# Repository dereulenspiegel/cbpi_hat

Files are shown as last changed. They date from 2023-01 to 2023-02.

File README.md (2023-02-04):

# CraftBeerPi Hat
This is a Raspberry Pi hat meant for use with [CraftBeerPi](https://github.com/craftbeerpi/craftbeerpi4).
It's created with [EasyEDA](https://easyeda.com/) and optimized for production via 
[JLCPCB](https://jlcpcb.com/).

This project is [certified](https://certification.oshwa.org/de000132.html) as open source
hardware by the [OSHWA](https://www.oshwa.org/) under the UID DE000132.

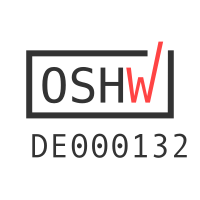
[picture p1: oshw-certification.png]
OSHWA certifcation logo


## Development

Currently this project is designed with [EasyEDA](https://easyeda.com/). You can find
all necessary files in the folder `easyeda`. When modifying this project please
respect the CERN-OHL-S license used in this project.

## Features

* Slots for up to 5 MAX31865 modules for PT100/PT1000 measurements
* 7 digital outputs with up to 1 amp of output power
* All 7 outputs have flyback diodes to drive inductive loads like solenoids
* All 7 outputs have resettable fuses for extra protection
* RTC so the Raspberry Pi doesn't loose its time in offline installations
* QWIIC connector to hookup additional sensors and actors following the 
  SparkFun QWIIC specification
* OneWire connection for additional sensors
* Can operate on 12-24V, digital outputs operate directly on input voltage
* Reverse voltage protection (but please be still be careful)

Please note that the digital outputs are inverted in logic due to the push pull stage, but
CraftBeerPi supports inverting GPIO actors.

# Polarity of connectors!!!

This board is powered by 12-24V and provides some reverse polarity protection. But still
please be careful when wiring up the board. Looking at the front of a connector the left
side of a connector is always the negative side and the right side of a connector is always
the positive side!

PCB:

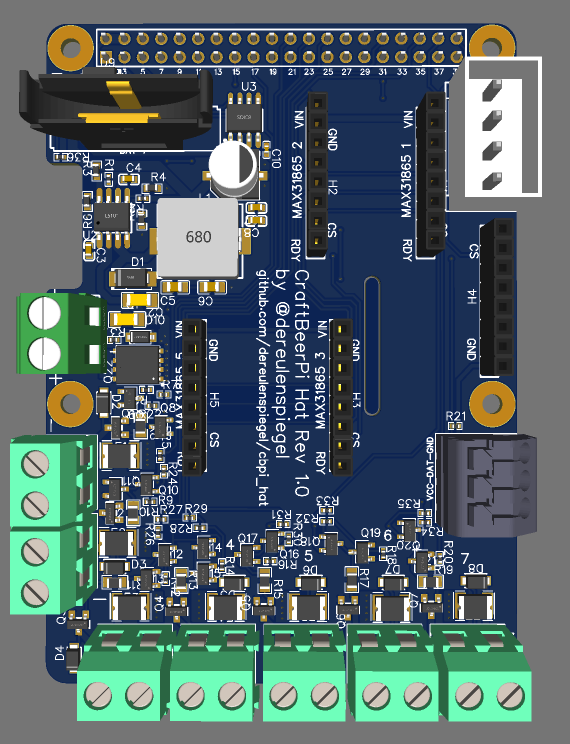
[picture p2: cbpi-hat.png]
Image of PCB rendering


Schematic:

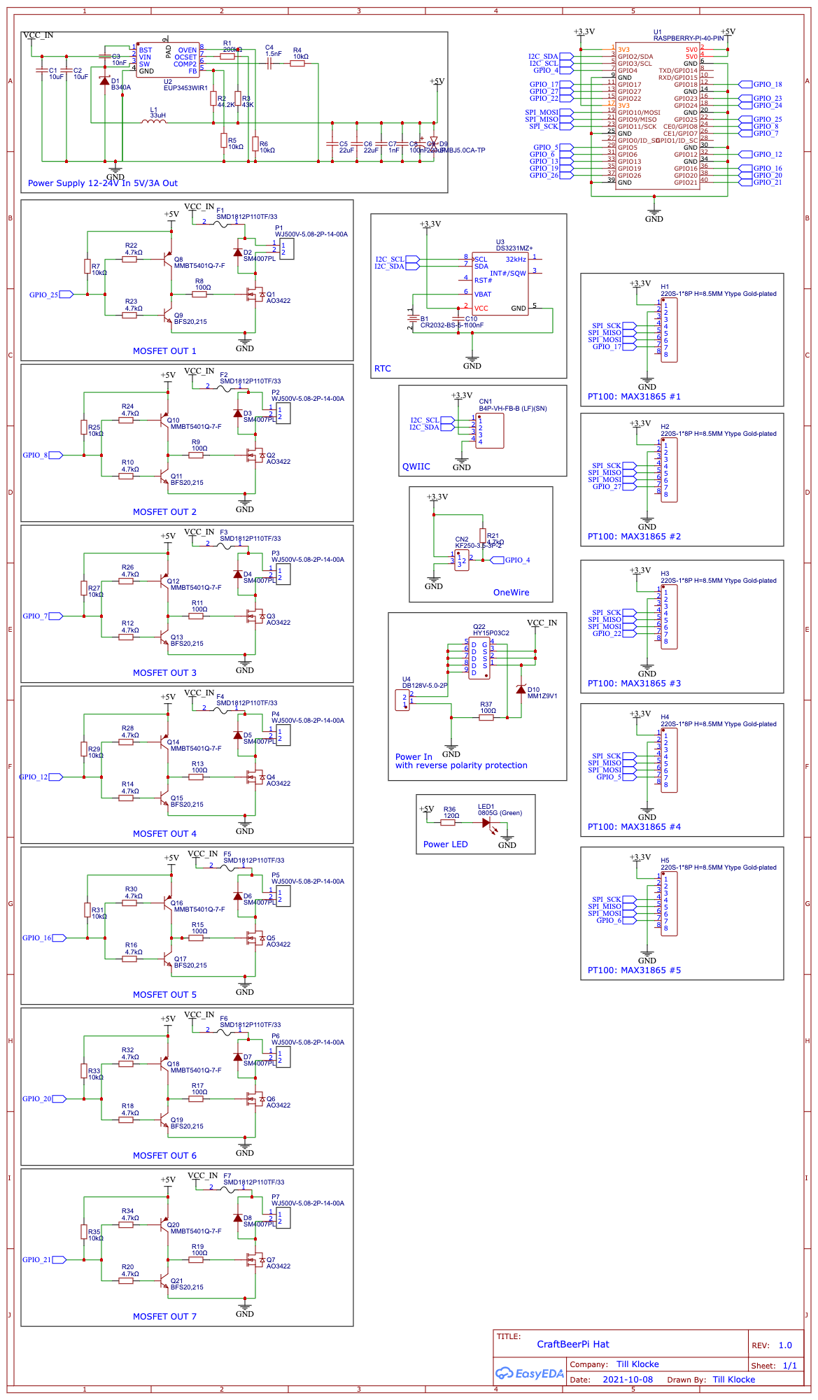
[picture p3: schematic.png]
Schematic


## PIN configuration

### Digital outputs

Digital outputs are counted starting on the most left. Outputs 2,3 and 7 are marked on the edge of
the PCBs upper layer. On the bottom layer every output is numbered and the polarity marked. On the
upper layer polarity markings are only next to the outer most ports on each side. But polarity is
always left side negative, right side positive.

| Output # | GPIO |
|---|---|
| 1 | 25 |
| 2 |  8 |
| 3 |  7 |
| 4 | 12 |
| 5 | 16 |
| 6 | 20 |
| 7 | 21 |

### MAX31865 modules

The MAX31865 modules are connected via SPI and each have a different CS-Pin. Modules
1,2,3,5 are mounted with the upper side facing left (towards the power connector and the SD-card
slot of the Raspberry Pi). Module 5 is flipped 180°. Every module connector has the first two and
last two pins marked with the same markings as the module to ensure the correct orientation.

| Modules # | GPIO CS |
|---|---|
| 1 | 17 |
| 2 | 27 |
| 3 | 22 |
| 4 |  5 |
| 5 |  6 |

### OneWire

The OneWire data line is connected to `GPIO 4`. The pins on the connector are marked behind the connector
on the top side of the PCB. They are, from left to right `VCC` - `DAT` - `GND`. A 4.7k pull up is
already provided on the board.
To enable OneWire support on a Raspberry Pi you need to add
```
dtoverlay=w1-gpio,gpiopin=4
```
to your config.txt

### RealTime Clock

The RTC (DS3231) is connected via I2C and should be usable by adding
```
dtparam=i2c_arm=on
dtoverlay=i2c-rtc,ds3231
```
to your config.txt

## Known Caveats

### Revision 1.0

* On revision 1.0 outputs 2 and 3 are mapped to chip enable pins of SPI0. Users need to disable CE pins on SPI0
* On revision 1.0 outputs are not in the desired off state during and directly after boot

To solve these issues the Raspberry Pi can be configured via config.txt.
With adding `dtoverlay=spi0-0cs` to the config.txt you can disable the hardware CE pins for SPI 0, freeing up GPIO 7 and 8
making Output 2 and 3 freely usabel.
With `gpio=25,7,8,12,16,20,21=op,dh` in the config.txt we set all pins controlling powered outputs to output and pull them high
as early as possible to disable the outputs. During power on there might be less than a second where the outputs might be enabled.

## Full config.txt additions for this board

```
# Enable SPI
dtparam=spi=on
# Enable 1-Wire
dtoverlay=w1-gpio,gpiopin=4
# Enable RTC
dtparam=i2c_arm=on
dtoverlay=i2c-rtc,ds3231
# Disable SPI0 CE pins
dtoverlay=spi0-0cs
# Disable outputs on boot
gpio=25,7,8,12,16,20,21=op,dh
```

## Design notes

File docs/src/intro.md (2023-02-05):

# Introduction

This CraftBeerPi Hat is mainly intended for brewery automation. It can be used for other use cases
involving digital outputs and sensor inputs, however this is out of scope of this project.
The hat should be compatible with other Single Board Computer systems following the 40 pin GPIO
layout introduced by the Raspberry Pi, but this is not guaranteed and untested.

The Hat has currently the following features:

* Input voltage of 12V - 24V
* DC-DC converter to power the Raspberry Pi from input voltage
* Reverse voltage protection on input
* Digital outputs operate on input voltage and provide up to 1 amp of output current
* Digital outputs are secured by flyback diode to be able to switch inductive loads
* Digital outputs are secured by a PTC resettable fuse to protect from over currents
* RTC for the Raspberry Pi
* OneWire connector to add additional sensors
* Possibility to mount a QWIIC connector for additional sensors and actors
* 5 slots for MAX31865 PT100/PT1000 converter

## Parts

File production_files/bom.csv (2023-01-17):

ID | Name | Designator | Footprint | Quantity | Manufacturer Part | Manufacturer | Supplier | Supplier Part | Price
1 | MM1Z9V1 | D10 | SOD-123_L2.7-W1.6-LS3.7-RD | 1 | MM1Z9V1 | ST(先科) | LCSC | C87636 | 0.002
2 | HY15P03C2 | Q22 | DFN-8_L5.9-W5.2-P1.27-LS6.2-BL | 1 | HY15P03C2 | HUAYI(华羿微) | LCSC | C123687
3 | 100Ω | R37 | R0402 | 1 | 0402WGF1000TCE | UNI-ROYAL(厚声) | LCSC | C25076
4 | 0805G (Green) | LED1 | LED0805-RD_GREEN | 1 | KT-0805翠绿 (SMT业务专用) | null | LCSC | C2297
5 | 120Ω | R36 | R0402 | 1 | 0402WGF1200TCE | UNI-ROYAL(厚声) | LCSC | C25079
6 | 1nF | C7 | C0603 | 1 | CC0603KRX7R9BB102 | YAGEO(国巨) | LCSC | C100040
7 | 100nF | C8 | C0603 | 1 | 0603B104K500NT | FH(风华) | LCSC | C30926
8 | 220uF | C9 | CAP-SMD_BD6.3-L6.6-W6.6-FD | 1 | RVE1A221M0605 | ROQANG(容强) | LCSC | C131120 | 0.008
9 | SMBJ5.0CA-TP | D9 | SMB_L4.6-W3.6-LS5.3-BI | 1 | SMBJ5.0CA-TP | MCC(美微科) | LCSC | C78757
10 | SMD1812P110TF/33 | F1,F2,F3,F4,F5,F6,F7 | F1812 | 7 | SMD1812P110TF/33 | RUILON(瑞隆源) | LCSC | C21000 | 0.02
11 | MMBT5401Q-7-F | Q8,Q10,Q12,Q14,Q16,Q18,Q20 | SOT-23-3_L3.0-W1.7-P0.95-LS2.9-BR | 7 | MMBT5401Q-7-F | DIODES(美台) | LCSC | C81569
12 | BFS20,215 | Q9,Q11,Q13,Q15,Q17,Q19,Q21 | SOT-23-3_L2.9-W1.6-P1.90-LS2.8-BR | 7 | BFS20,215 | Nexperia(安世) | LCSC | C73088
13 | 10kΩ | R7,R25,R27,R29,R31,R33,R35 | R0402 | 7 | 0402WGF1002TCE | UNI-ROYAL(厚声) | LCSC | C25744
14 | 4.7kΩ | R10,R12,R14,R16,R18,R20,R22,R23,R24,R26,R28,R30,R32,R34,R21 | R0402 | 15 | 0402WGF4701TCE | UNI-ROYAL(厚声) | LCSC | C25900
15 | KF250-3.5-3P-2 | CN2 | CONN-TH_3P-P3.50_KF250-3.5-3P-2 | 1 | KF250-3.5-3P-2 | Cixi Kefa Elec | LCSC | C475164 | 0.029
16 | CR2032-BS-5-1 | B1 | BAT-TH_CR2032-BS-5-1 | 1 | CR2032-BS-5-1 | Q&J | LCSC | C70379 | 0.018
17 | 10uF | C1,C2 | C1206 | 2 | CL31A106KBHNNNE | SAMSUNG(三星) | LCSC | C13585 | 0.005
18 | 10nF | C3 | C0603 | 1 | 0603B103K500NT | FH(风华) | LCSC | C57112
19 | 1.5nF | C4 | C0603 | 1 | 0603B152K500NT | FH(风华) | LCSC | C1595 | 0.001
20 | 22uF | C5,C6 | C0805 | 2 | CL21A226MAQNNNE | SAMSUNG(三星) | LCSC | C45783 | 0.004
21 | B4P-VH-FB-B (LF)(SN) | CN1 | CONN-TH_B4P-VH-FB-B-LF-SN | 1 | B4P-VH-FB-B(LF)(SN) | JST | LCSC | C157995 | 0.043
22 | B340A | D1 | SMA_L4.3-W2.6-LS5.2-RD | 1 | B340A | MDD | LCSC | C64982 | 0.007
23 | SM4007PL | D2,D3,D4,D5,D6,D7,D8 | SOD-123F_L2.8-W1.8-LS3.7-RD | 7 | SM4007PL | MDD | LCSC | C64898 | 0.001
24 | 220S-1*8P H=8.5MM Ytype Gold-plated | H1,H2,H3,H4,H5 | HDR-TH_8P-P2.54-V-F-1 | 5 | 220S-1*8P H=8.5MM Ytype Gold-plated | Ckmtw | LCSC | C124416 | 0.023
25 | 33uH | L1 | IND-SMD_L11.5-W10.0 | 1 | SMMS1050-330M | SXN(顺翔诺) | LCSC | C149547 | 0.045
26 | WJ500V-5.08-2P-14-00A | P1,P2,P3,P4,P5,P6,P7 | CONN-TH_2P-P5.00_WJ500V-5.08-2P | 7 | WJ500V-5.08-2P | KANGNEX(康奈克斯电气) | LCSC | C8465 | 0.018
27 | AO3422 | Q1,Q2,Q3,Q4,Q5,Q6,Q7 | SOT-23_L2.9-W1.3-P1.90-LS2.4-BR | 7 | AO3422 | AOS | LCSC | C37130 | 0.036
28 | 200kΩ | R1 | R0402 | 1 | AR02BTC2003 | Viking(光颉) | LCSC | C317930 | 0.004
29 | 44.2K | R2 | R0402 | 1 | AC0402FR-0744K2L | YAGEO(国巨) | LCSC | C227086
30 | 43K | R3 | R0603 | 1 | RC0603FR-0743KL | YAGEO(国巨) | LCSC | C137719
31 | 10kΩ | R4,R5,R6 | R0603 | 3 | RMC060310KFN | Tyohm(幸亚电阻) | LCSC | C269701
32 | 100Ω | R8,R9,R11,R13,R15,R17,R19 | R0805 | 7 | 0805W8F1000T5E | UNI-ROYAL(厚声) | LCSC | C17408
33 | EUP3453WIR1 | U2 | SOIC-8_L4.9-W3.9-P1.27-LS6.0-BL-EP3.1 | 1 | EUP3453WIR1 | Eutech Microelectronics | LCSC | C311687
34 | DS3231MZ+ | U3 | SOIC-8_L4.9-W3.9-P1.27-LS6.0-BL | 1 | DS3231MZ+TRL | MAXIM(美信) | LCSC | C107410 | 0.816
35 | DB128V-5.0-2P | U4 | CONN-TH_2P-P5.00_DB128V-5.0-2P | 1 | DB128V-5.0-2P | DIBO | LCSC | C395860 | 0.023
36 | RASPBERRY-PI-40-PIN | U1 | 2*20P_RASPBERRY_PI_HEADER | 1 | C35165 | BOOMELE | LCSC | C35165 | 0.159
37 | 100nF | C10 | C0402_NEW | 1 | CL05B104KO5NNNC | SAMSUNG(三星) | LCSC | C1525

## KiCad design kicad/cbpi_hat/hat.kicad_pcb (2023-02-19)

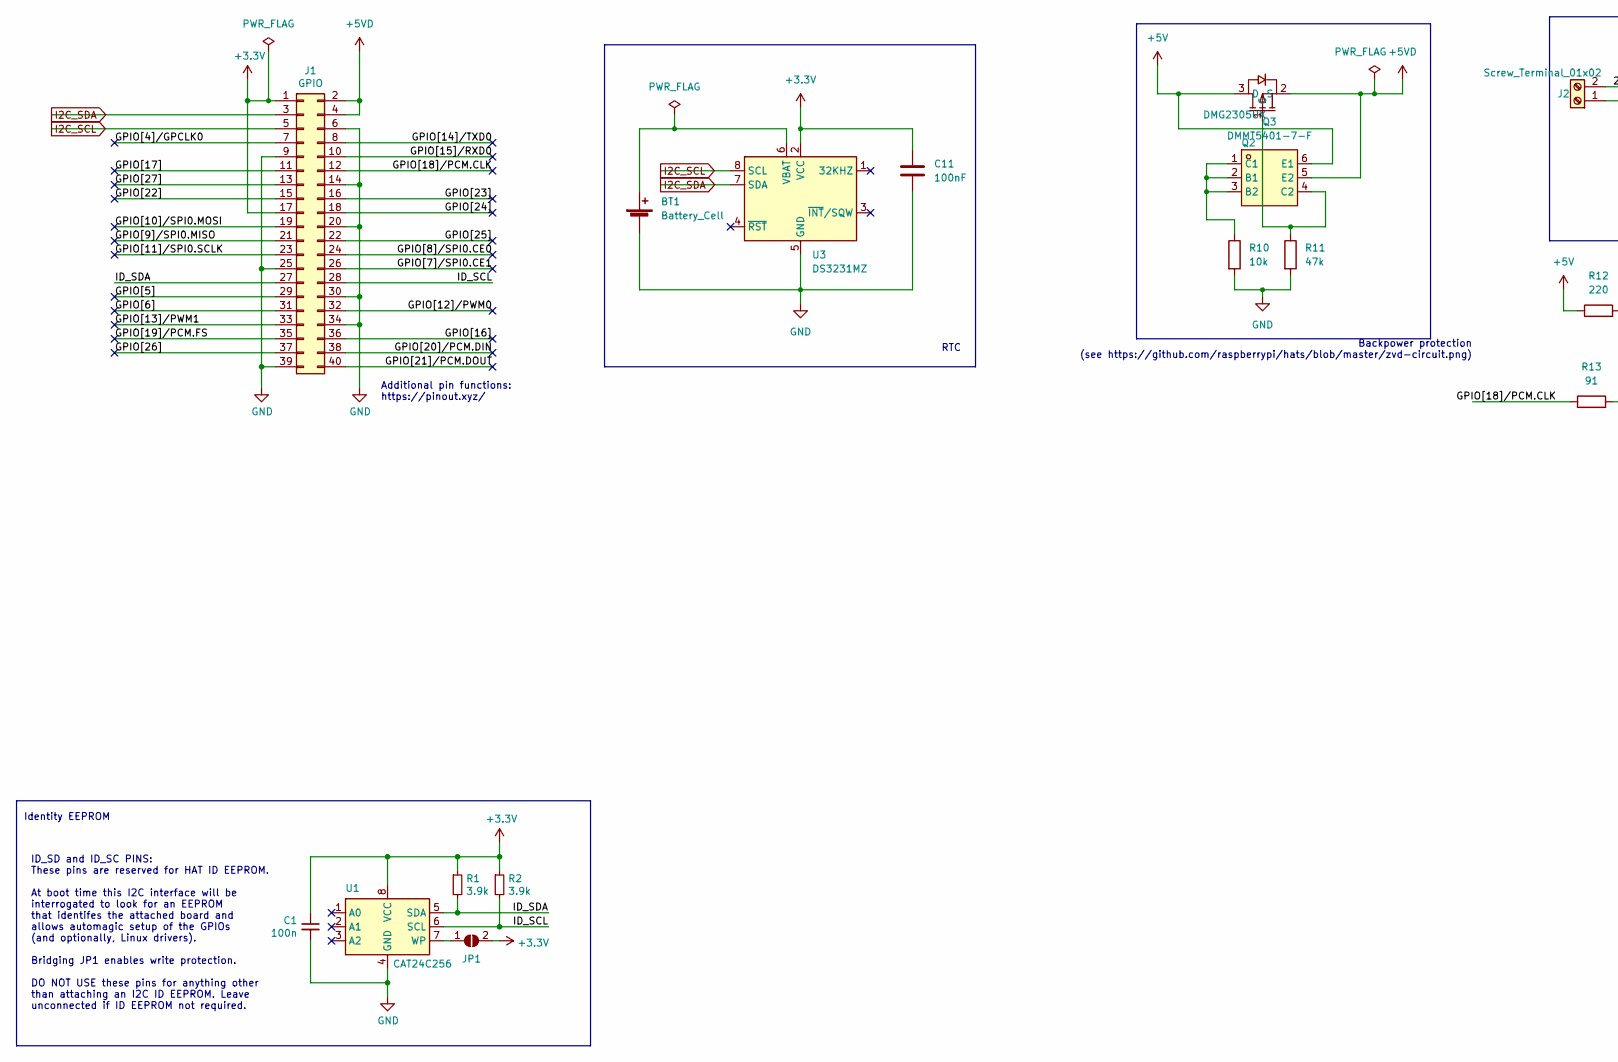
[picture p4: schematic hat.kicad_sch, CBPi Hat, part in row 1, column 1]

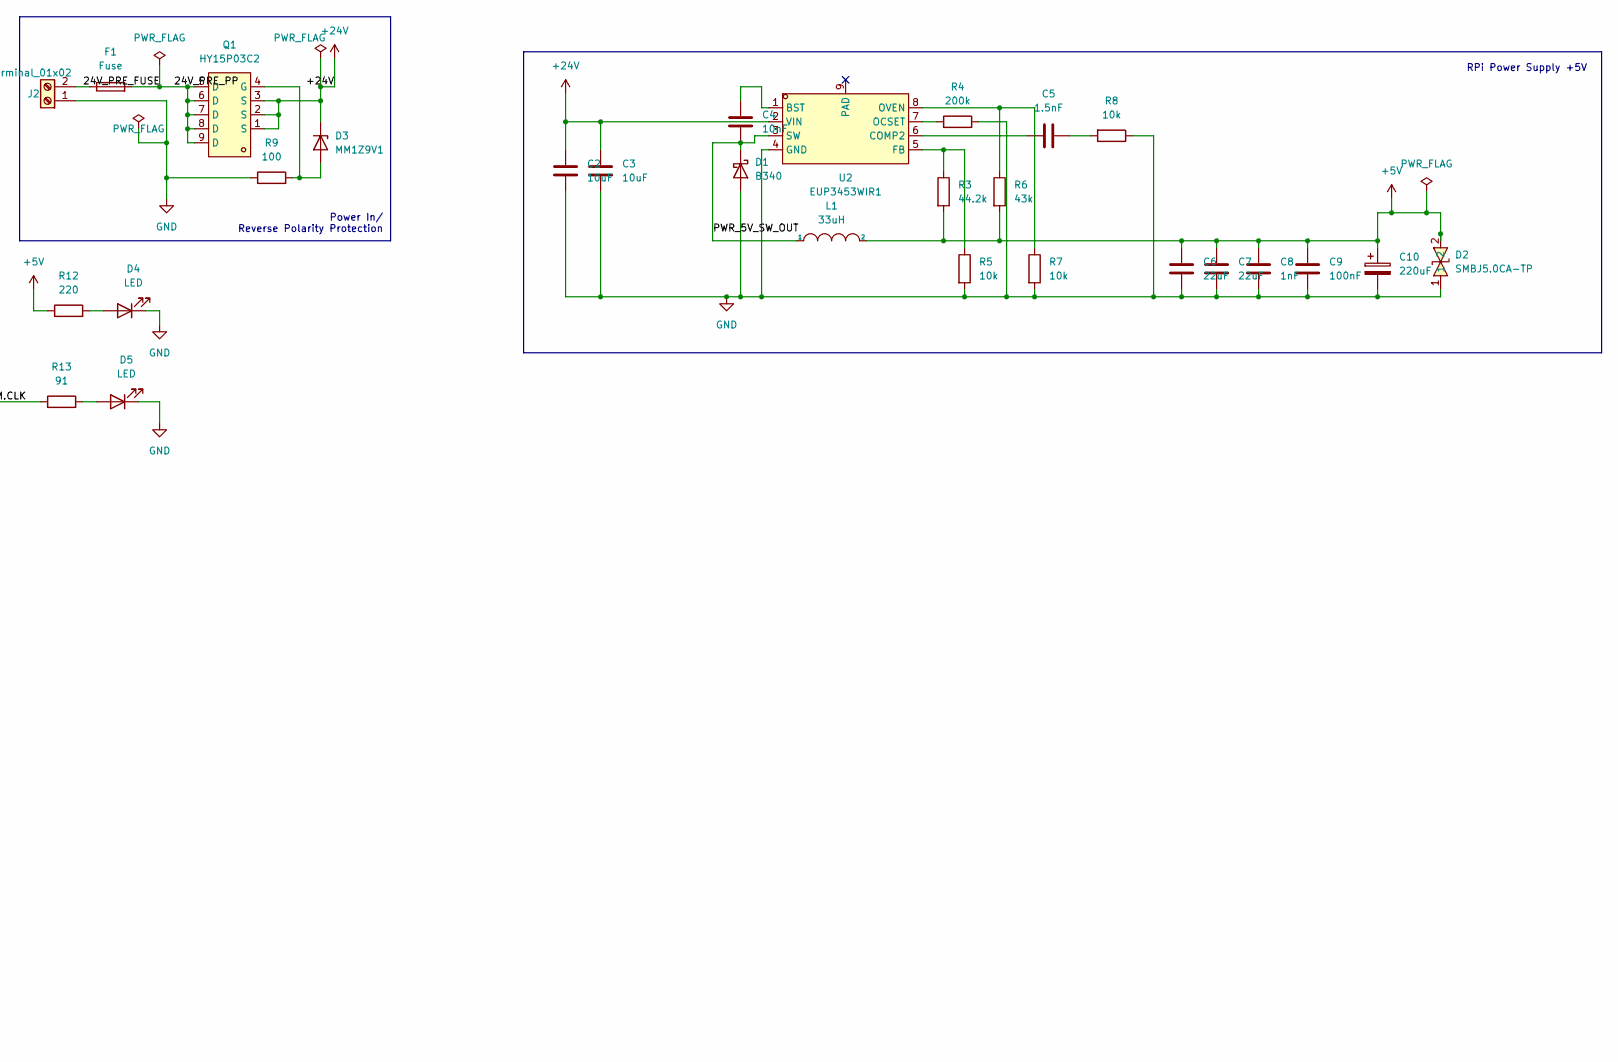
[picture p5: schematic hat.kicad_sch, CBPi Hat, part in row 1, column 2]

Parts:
BT1: Battery_Cell; BAT-TH_CR2032-BS-5-1
C1: 100n; C_0603_1608Metric
C2, C3: 10uF; C_1206_3216Metric
C4: 10nF; C_0603_1608Metric
C5: 1.5nF; C_0603_1608Metric
C6, C7: 22uF; C_0805_2012Metric
C8: 1nF; C_0603_1608Metric
C9, C11: 100nF; C_0603_1608Metric
C10: 220uF; C_Elec_6.3x5.4
D1: B340; D_SMA
D2: SMBJ5.0CA-TP; SMB_L4.6-W3.6-LS5.3-BI; LCSC Part C78757
D3: MM1Z9V1; D_SOD-123
D4, D5: LED; LED_0603_1608Metric
F1: Fuse; Fuse_Blade_ATO_directSolder
J1: GPIO; PinSocket_2x20_P2.54mm_Vertical
J2: Screw_Terminal_01x02; TerminalBlock_Altech_AK300-2_P5.00mm
JP1: ID_WP; SolderJumper-2_P1.3mm_Open_RoundedPad1.0x1.5mm
L1: 33uH; IND-SMD_L11.5-W10.0
Q1: HY15P03C2; DFN-8_L5.9-W5.2-P1.27-LS6.2-BL; LCSC Part C123687
Q2: DMG2305UX; SOT-23-3_L2.9-W1.3-P0.95-LS2.4-BR-1; LCSC Part C2940629
Q3: DMMT5401-7-F; SOT-23-6_L2.9-W1.6-P0.95-LS2.8-BR; LCSC Part C154733
R1, R2: 3.9k; R_0402_1005Metric
R3: 44.2k; R_0402_1005Metric
R4: 200k; R_0402_1005Metric
R5, R7, R8: 10k; R_0603_1608Metric
R6: 43k; R_0603_1608Metric
R9: 100; R_0402_1005Metric
R10: 10k; R_0402_1005Metric
R11: 47k; R_0402_1005Metric
R12: 220; R_0402_1005Metric
R13: 91; R_0402_1005Metric
U1: CAT24C256; SOIC-8-1EP_3.9x4.9mm_P1.27mm_EP2.29x3mm
U2: EUP3453WIR1; SOIC-8_L4.9-W3.9-P1.27-LS6.0-BL-EP3.1; LCSC Part C311687
U3: DS3231MZ; SOIC-8_3.9x4.9mm_P1.27mm

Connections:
+3.3V: C1.1, C11.1, J1.1, J1.17, JP1.2 (B), R1.1, R2.1, U1.8 (VCC), U3.2 (VCC)
+5V: C6.1, C7.1, C8.1, C9.1, C10.1, D2.2, L1.2, Q2.3 (D), Q3.6 (E1), R3.2, R6.2, R12.1
+5VD: J1.2, J1.4, Q2.2 (S), Q3.5 (E2)
+24V: C2.1, C3.1, D3.1 (K), Q1.1 (S), Q1.2 (S), Q1.3 (S), U2.2 (VIN)
/24V_PRE_FUSE: F1.1, J2.2
/24V_PRE_PP: F1.2, Q1.5 (D), Q1.6 (D), Q1.7 (D), Q1.8 (D), Q1.9 (D)
/GPIO[4]/GPCLK0: J1.7
/GPIO[5]: J1.29
/GPIO[6]: J1.31
/GPIO[7]/SPI0.CE1: J1.26
/GPIO[8]/SPI0.CE0: J1.24
/GPIO[9]/SPI0.MISO: J1.21
/GPIO[10]/SPI0.MOSI: J1.19
/GPIO[11]/SPI0.SCLK: J1.23
/GPIO[12]/PWM0: J1.32
/GPIO[13]/PWM1: J1.33
/GPIO[14]/TXD0: J1.8
/GPIO[15]/RXD0: J1.10
/GPIO[16]: J1.36
/GPIO[17]: J1.11
/GPIO[18]/PCM.CLK: J1.12, R13.1
/GPIO[19]/PCM.FS: J1.35
/GPIO[20]/PCM.DIN: J1.38
/GPIO[21]/PCM.DOUT: J1.40
/GPIO[22]: J1.15
/GPIO[23]: J1.16
/GPIO[24]: J1.18
/GPIO[25]: J1.22
/GPIO[26]: J1.37
/GPIO[27]: J1.13
/ID_SCL: J1.28, R2.2, U1.6 (SCL)
/ID_SDA: J1.27, R1.2, U1.5 (SDA)
/PWR_5V_SW_OUT: C4.2, D1.1 (K), L1.1, U2.3 (SW)
GND: BT1.2 (-), C1.2, C2.2, C3.2, C6.2, C7.2, C8.2, C9.2, C10.2, C11.2, D1.2 (A), D2.1, D4.1 (K), D5.1 (K), J1.6, J1.9, J1.14, J1.20, J1.25, J1.30, J1.34, J1.39, J2.1, R4.2, R5.2, R7.2, R8.1, R9.1, R10.2, R11.2, U1.4 (GND), U2.4 (GND), U3.5 (GND)
I2C_SCL: J1.5, U3.8 (SCL)
I2C_SDA: J1.3, U3.7 (SDA)
unnamed: BT1.1 (+), U3.6 (VBAT)
unnamed: C4.1, U2.1 (BST)
unnamed: C5.1, U2.6 (COMP2)
unnamed: C5.2, R8.2
unnamed: D3.2 (A), Q1.4 (G), R9.2
unnamed: D4.2 (A), R12.2
unnamed: D5.2 (A), R13.2
unnamed: JP1.1 (A), U1.7 (WP)
unnamed: Q2.1 (G), Q3.4 (C2), R11.1
unnamed: Q3.1 (C1), Q3.2 (B1), Q3.3 (B2), R10.1
unnamed: R3.1, R5.1, U2.5 (FB)
unnamed: R4.1, U2.7 (OCSET)
unnamed: R6.1, R7.1, U2.8 (OVEN)

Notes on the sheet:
Additional pin functions: https://pinout.xyz/
Identity EEPROM
ID_SD and ID_SC PINS: These pins are reserved for HAT ID EEPROM. At boot time this I2C interface will be interrogated to look for an EEPROM that identifes the attached board and allows automagic setup of the GPIOs (and optionally, Linux drivers). Bridging JP1 enables write protection. DO NOT USE th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
RTC
Backpower protection (see https://github.com/raspberrypi/hats/blob/master/zvd-circuit.png)
RPi Power Supply +5V
Power In/ Reverse Polarity Protection

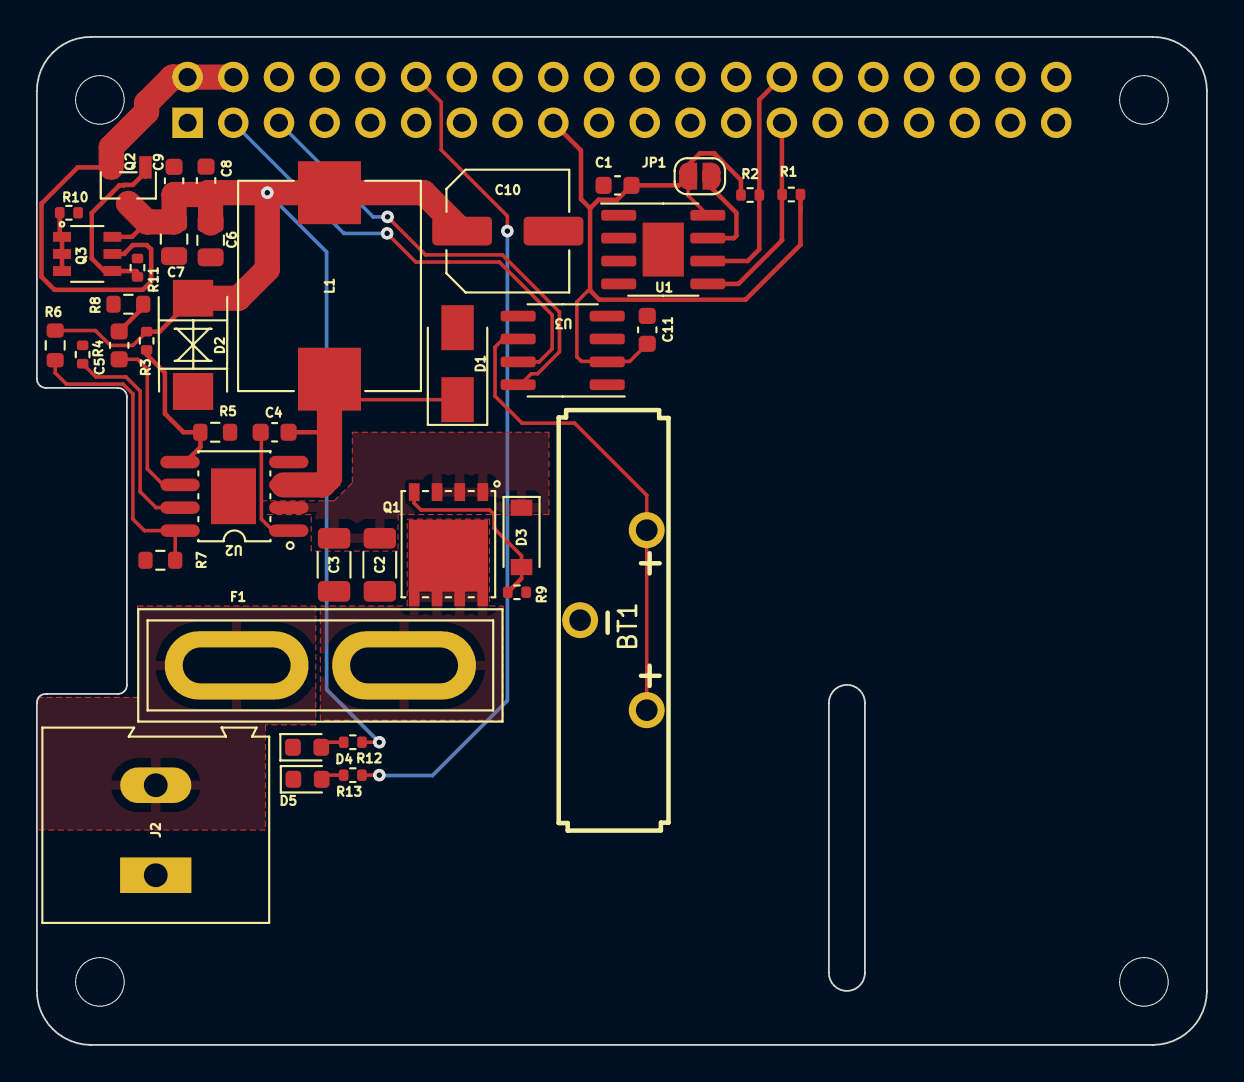
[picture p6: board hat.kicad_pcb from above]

Board: 2 copper layers, 65.0 x 56.0 mm, 45 parts (1 on the bottom side), 26 nets.

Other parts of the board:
MH1, MH2, MH3, MH4: MountingHole_2.7mm_M2.5

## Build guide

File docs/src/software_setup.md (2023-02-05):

# Software setup

To properly operate this board and make use of all its features a few things need to be
considered on the software side as well.

## RTC

The RTC on this board is a DS3231 and well supported by all Linux kernels. To make use of the RTC
you need to enable I2C and use the proper devive tree overlay to let the kernel know about the
availability of the RTC. To do this simply add the lines to the `config.txt` of your Raspberry Pi
installation

```
dtparam=i2c_arm=on
dtoverlay=i2c-rtc,ds3231
```

## OneWire

OneWire support needs to be enabled as well for the kernel to be usable by userland applicartions like
CraftBeerPi. The OneWire data line is connected to `GPIO4` on the Raspberry Pi. To enable OneWire support
simply add the following line to your `config.txt`

```
dtoverlay=w1-gpio,gpiopin=4
```

## SPI (MAX31865)

The MAX31865 modules are connected via SPI on the bus SPI0 on the Raspberry Pi. To enable SPI support
add the following lines to your `config.txt`

```
dtparam=spi=on
dtoverlay=spi0-0cs
```

We need to disable the chip enable pins of the SPI0 bus, because they would only support 2 devices and
this board supports up to 5 MAX31865. The GPIO formerly used as chip enable are used to control output
2 and 3.

When configuring the MAX31865 modules in CraftBeerPi you need to specify the chip enable pin for each
module. The following table maps the numbered module slot to the correct GPIO serving as the chip enable
pin:

| Module # | GPIO CS |
|---|---|
| 1 | 17 |
| 2 | 27 |
| 3 | 22 |
| 4 |  5 |
| 5 |  6 |

## GPIO

The digital outputs are controlled by GPIO pins. Please note that the outputs are inverted, meaning that if
the GPIO is high the output is disabled and vice versa. To bring the GPIO pins controlling the outputs as soon
as possible in a defined high state and therefore disabling the outputs during boot please add the following
line to your `config.txt`

```
gpio=25,7,8,12,16,20,21=op,dh
```

When configuring GPIO actors in CraftBeerPi please ensure that you specify "Yes" for the field "Inverted"!
The following table maps the GPIO pin numbers to the numbered outputs

| Output # | GPIO |
|---|---|
| 1 | 25 |
| 2 |  8 |
| 3 |  7 |
| 4 | 12 |
| 5 | 16 |
| 6 | 20 |
| 7 | 21 |

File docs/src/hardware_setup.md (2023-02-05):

# Hardware Setup

The board itself has been designed with ease of use in mind. However certain things need
to be considered.

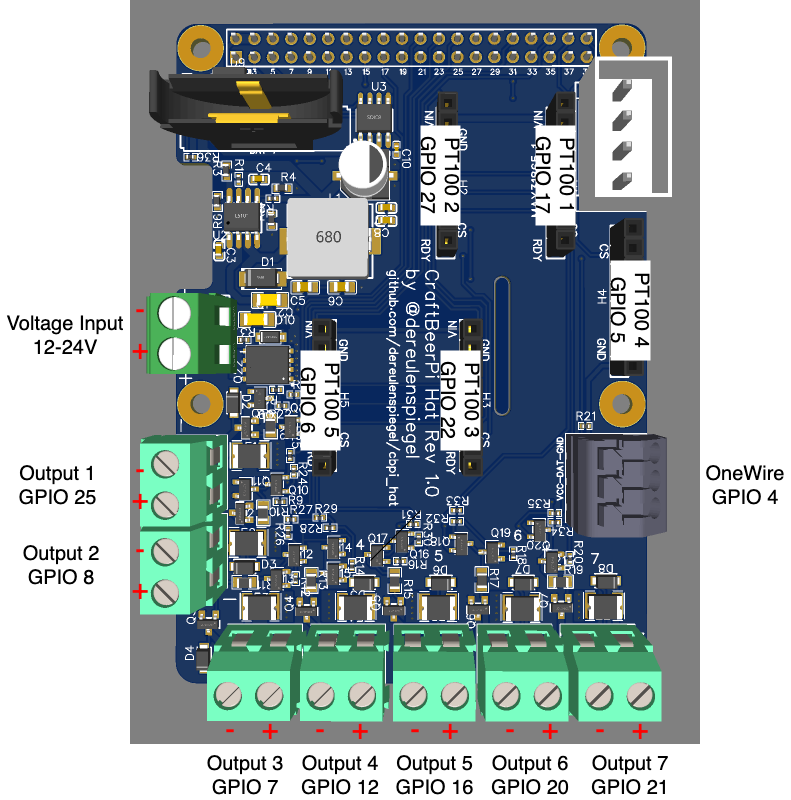
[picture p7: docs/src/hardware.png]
Overview


## Power

First of all please use a proper power supply to power the board. In theory every output
can provide up to 1 amp and the Rasperry Pi could draw up to 3 amp. So in total the board might
require up to 10 amp to be provided by the PSU. Please calculate your actual power requirements
and provide proper fusing on the power input as currently only the outputs have fuses but not
the overall board itself.

When deciding for the voltage it is best to consider what voltage you need on the outputs as the 
outputs will directly output the input voltage. The hat will convert every input voltage between
12V and 24V into 5V for the Raspberry Pi. There is no need to power the Raspberry Pi through USB.
So please do not power the Raspberry Pi via USB when using the hat, as this might damage the
Raspberry Pi and/or the hat.

## Polarity

Even though the board has reverse voltage protection on its input, polarity is important for
successful operation. When looking at the front of a screw terminal the negative side is always left
and the positive side is always right. This is true for the input connector and all output screw 
terminals. There are also markings `+` and `-` next to connectors if there is space for that on the
top side. On the bottom side the polarity and numbering of all connectors is marked in full.

## MAX31865 for PT100/PT1000

On the board are five slots for MAX31865 modules like the ones from [Adafruit](https://www.adafruit.com/product/3328).
Slots 1,2,3 and 5 are oriented in the same direction with the MAX31865 modules top side facing to the left. Slot 4 is
reversed for space saving reasons and is therefore facing to the right.

In CraftBeerPi you need to configure for each module you have plugged in and want to use the correct chip enable.
The GPIOs used as chip enable for each slot are marked in the overview picture, but here is additionally a handy
table:

| Module # | GPIO CS |
|---|---|
| 1 | 17 |
| 2 | 27 |
| 3 | 22 |
| 4 |  5 |
| 5 |  6 |

## RTC

For the RTC to properly work you need to insert a CR2032 battery into the battery holder. The polarity is marked on the board.

## Outputs

The board has 7 different powered outputs to drive GPIO actors. Every output outputs the input voltage with up to 1 amp to drive
SSRs, relays, solenoids etc. For loads like relays and solenoids the polarity should not matter. For other loads the polarity is the
same as on the input (left negative side, right positive side).

**All outputs are inverted, meaning that they are active when the GPIO is driven low and vice versa!**  
**Ensure that you select "Inverted" "Yes" when configuring the GPIO actor in CraftBeerPi!**

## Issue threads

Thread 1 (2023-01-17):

Redesign this board in KiCAD

dereulenspiegel, 2023-01-17:
While EasyEDA is a wonderful and easy to use tool, it is unfortunately not open source and in some aspects quite limited. To not limit this project by the abilities of EasyEDA and to not depend on closed source software it makes sense to port the design files to KiCAD. The ability to easily produce this design via JLCPCB should be kept, so a useful integration between KiCAD and the JLCPCB libraries and processes is necessary.

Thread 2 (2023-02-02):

Buzzer and physical buttons connectors

smillier, 2023-02-02:
Hello,

Would it be possible to add a buzzer on the board, ideally on GPIO25 as it's default on CraftbeerPi ?
Another great thing would be to add connectors for let's say 4 physical buttons that can then be assigned to tasks in CraftbeerPi. Is that something you tought of ?

dereulenspiegel, 2023-02-03:
A buzzer sounds like a good idea and I actually had thought of that, unfortunately only after I placed the order. Buttons sound useful too, but I am a bit worried about the placement. I try to keep the board as small as possible and to optimize it to be installed in some kind of casing.

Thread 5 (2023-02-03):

Reverify default pin states

dereulenspiegel, 2023-02-03:
It seems that we haven't achieved the desired outcome that all outputs are switched off during and directly after boot. We need to fix that in the future.

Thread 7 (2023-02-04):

[Rev 1.0] verify gate control voltage for output MOSFETs

dereulenspiegel, 2023-02-04:
Currently it seems that switched off outputs still output about 2V with 24V input voltage. We need to verify whether that is a critical bug and how we fix that in the next revision.

dereulenspiegel, 2023-02-05:
The ~2V measured in the switched off state don't seem to matter. As soon as there is a small load the voltage drops to a few hundred mV and on larger loads probably drops even further.
This behavior should be sufficient and safe for the intended operation.

Closed 2023-02-05.

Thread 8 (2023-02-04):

Pull Up only against 3.3V not 5V

dereulenspiegel, 2023-02-04:
In the latest schematic we pull up the output GPIOs against 5V. This is of course wrong. We need to pull them up to 3.3V instead.

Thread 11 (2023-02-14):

Add support for official touchscreen display

dereulenspiegel, 2023-02-14:
The official touchscreen display requires to connect the touchscreen component via I2C. We should expose a pin header with 5V, GND, interrupt pin and I2C so the official display can easily be connected.

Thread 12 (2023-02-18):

Add protection diode to avoid backpowering issues

dereulenspiegel, 2023-02-18:
This HAT is backpowering the Pi through the GPIO header. As the user might still have USB power supplied to the Pi vor various reasons we should a circuit as described [here](https://github.com/raspberrypi/hats/blob/master/zvd-circuit.png) to avoid issues.

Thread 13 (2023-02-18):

Add error LED

dereulenspiegel, 2023-02-18:
The CBPi setup might run into problems rather early in the bootstage not being able to start the web ui. So it might be nice to have a LED indicating errors at that stage.

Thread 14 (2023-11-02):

Has it been tested in real life ?

smillier, 2023-11-02:
Hello,

I'm upgrading my controler and would like to know if this hat has been tested in real life ? Are there anything I need to do on the assembly / pcb  to use it ?
Have you tested the ADC part with MAX31865 ?

Thanks!

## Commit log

2023-01-02 “root”
2023-01-02 Added image of schematic
2023-01-02 Added exports of production files
    [bom.csv, pick_and_place.csv]
2023-01-02 Added pin documentation
2023-01-03 minor upgrades, mostly regarding text and documentation on the board. Improved resistors on MOSFET gates, so they don't form an unnecessary voltage divider
    [bom.csv, pick_and_place.csv]
2023-01-03 Updated exported pictures after board changes
2023-01-03 Updated EasyEDA exports after board changes
2023-01-09 Rather large change on the PCB introducing fuses on each output and a push pull schematic for more protection of the raspberry pi as well as pull up resistors to have a defined off state for every ou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
    [bom.csv, pick_and_place.csv]
2023-01-10 Board has now better protection in the 5V supply for the Raspberry Pi and a few optimizations and corrections in the silscreen layers and part placement
    [bom.csv, pick_and_place.csv]
2023-01-10 Added LTSpice circuit of the digital output to simulate and verify its behavior
2023-01-11 Added power indicator LED to 5V rail and further optimized a few parts placements
    [bom.csv, pick_and_place.csv]
2023-01-11 Accidentally pushed the wrong image image as pcb image
2023-01-11 Again a few minor changes in parts placement. Mostly to optimize readability of upper silkscreen
    [pick_and_place.csv]
2023-01-12 Optimized parts placement further and added reverse polarity protection, which hopefully works
    [bom.csv, pick_and_place.csv]
2023-01-12 Optimized parts placement for better ground planes, as we will pump up to 10 amps through this board
2023-01-13 More optimization on pcb traces running power, to minimize losses towards the Pi and possibly power hungry 1 wire devices
2023-01-13 Added missing capacitator to VCC on DS3231
    [bom.csv, pick_and_place.csv]
2023-01-13 Added documentation how to enable OneWire support on a Raspberry Pi
2023-01-13 Added top layer markings to easier identify the board
2023-01-13 Added missing capacitator
2023-01-15 A few more optimizations in parts and trace placement
    [pick_and_place.csv]
2023-01-17 The MOSFETs gates on the outputs are now controlled by 5V instead of 3.3V which should lower the internal resistance of the MOSFETs and give us more safety margin
    [bom.csv]
2023-02-05 Forgot that applefs is now case sensitive by default, but the fs on the github runner is
2023-02-11 Added empty kicad project
    [cbpi_hat.kicad_pcb, cbpi_hat.kicad_sch]
2023-02-11 Added smbj5.0 over voltage protection to project library
2023-02-11 Reimplemented the 5V power supply for the Raspberry Pi in KiCAD
    [cbpi_hat.kicad_sch]
2023-02-11 KiCAD wanted to save more changes
    [cbpi_hat.kicad_sch]
2023-02-13 Restarted the KiCAD design based on the official Hat template
    [cbpi_hat.kicad_pcb, cbpi_hat.kicad_sch, hat.kicad_pcb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]
2023-02-13 Added footprints etc. for the 33uH inductance
2023-02-13 Assigned all footprints to the DC DC converter
    [hat.kicad_sch]
2023-02-15 Added gitignore so we don't checkin the kicad backups anymore
    [hat.kicad_sch]
2023-02-15 Upadted pin definitions of library symbols to get rid of erc warnings
2023-02-15 We now have no erc errors or warnings for now
    [hat.kicad_sch]
2023-02-15 Added library for mosfet for the reverse polarity protection
2023-02-15 The schematic should now have the current reverse polarity proection
    [hat.kicad_sch]
2023-02-15 Placed first components on board, no routing yet
    [hat.kicad_pcb, hat.kicad_sch]
2023-02-18 5V DC-DC converter is largely routed including reverse polarity protection
    [hat.kicad_pcb]
2023-02-18 Added protection against back powering. This should fix #12
    [hat.kicad_pcb, hat.kicad_sch]
2023-02-18 DC-DC converter and identity eeprom should be fully routed now (except for GND).
    [hat.kicad_pcb, hat.kicad_sch]
2023-02-18 RTC is now in the schematic
    [hat.kicad_sch]
2023-02-18 RTC block is now annotated
    [hat.kicad_sch]
2023-02-18 Added RTC to board
    [hat.kicad_pcb, hat.kicad_sch]
2023-02-18 Added power and warning LED. This should address #13 and fix it
    [hat.kicad_pcb, hat.kicad_sch]
2023-02-19 Replaced CR2032 holder with the old more space saving one and fixed all DRC errors and warnings except for unconnected GND
    [hat.kicad_pcb, hat.kicad_sch]
